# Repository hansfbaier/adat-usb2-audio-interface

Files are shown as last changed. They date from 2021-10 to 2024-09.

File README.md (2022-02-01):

# ADAT USB Audio Interface

FPGA based USB 2.0 High Speed audio interface featuring multiple optical ADAT inputs and outputs

BlockDiagram

## Status / current limitations
* Enumerates as class compliant audio device on Windows and Linux (Mac OS not tested). 2 and 32 channel modes.
* Audio input and output seems to work glitch free.
* Only 48kHz sample rate supported
* Integrated USB2 high speed logic analyzer works
* Runs without dropouts with FlexASIO with a buffer size of 32 samples (0.67ms latency)
* Has a hardware roundtrip latency (USB out -> ADAT out -> cable -> ADAT in -> USB in)
  of 2-3 USB2 microframes which is about 0.25ms to 0.375 ms
* Both headphone DACs on the board work now. In two channel mode, they are both wired to channels 0/1.
  In 36 channel mode DAC1 is wired to channels 0/1 and DAC2 to channels 2/3
* Both USB PHYs now are operational. USB1 has access to all 32 ADAT I/Os and has 4 extra channels to/from USB2.
  USB2 enumerates as a 4-channel sound card which sends/receives audio to/from USB1
* Both USB interfaces will also enumerate as USB MIDI devices and send each other MIDI
* The current board design has not been designed with the case in mind: In the current version of the case,
  only ADAT-cables with thin connectors will fit into the holes. Cables with fat connectors will hit the case
  wall before they can be fully inserted. This will be fixed in a future iteration of the PCB and case.
* The current case design lacks a guide channel for the LED light pipes. Therefore there is considerable bleed
  from lightpipes into each other, and they also can't be positioned exactly over the LEDs.
  Will be fixed in the next version of the case.
* Limitation: Currently audio input will not work properly when audio output is inactive.
  This should not be a problem for most uses (VoIP, Videoconference, DAW recording).
  If you have an important use case which needs this, please file an issue.

## Hardware
The current board design is a custom development board,
based on the QMTech core FPGA boards.
Once the chip shortage is over, it is planned to move to
a complete custom design, including the FPGA.

P1173938



## How to build
1. Download and install [Intel Quartus Lite](https://fpgasoftware.intel.com/?edition=lite)
2. put the bin/ directory of Quartus into your PATH variable:
```bash
export PATH=$PATH:/opt/intelFPGA_lite/21.1/quartus/bin/
```
Of course you need to adjust this to the install directory and version of your particular installation.

3. Set up python venv and install requirements:
```bash
$ cd gateware/
$ ./initialize-python-environment.sh
$ cd ..
```

4. Activate the venv and build
```bash
$ source ./gateware/venv/bin/activate
$ python3 gateware/adat_usb2_audio_interface.py --keep
```

This will create a directory named build/ and after a successful build will directly
try to load the generated bitstream into the FPGA, if an USB-Blaster is connected.
Or, you can flash the bitstream manually, by opening the Quartus GUI with:
```bash
quartus build/*.qpf
```
and then open the programmer application from there.
Alternatively you could directly start the programmer with:
```bash
quartus_pgmw
```

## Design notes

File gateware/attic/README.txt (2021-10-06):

This directory contains platform files which are not maintained
anymore, but still can serve as examples on how to run on
other boards.

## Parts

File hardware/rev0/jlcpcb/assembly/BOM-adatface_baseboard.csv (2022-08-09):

Comment | Designator | Footprint | LCSC
10k | R10,R3,R4,R5,R6,R9 | R_0603_1608Metric | C25804
USB3320 | U5,U6 | QFN-32-1EP_5x5mm_P0.5mm_EP3.3x3.3mm | C132156
PLR135_T8 | U1,U2,U3,U4 | PLR135-T8_PLT133-T8 | C133351
47uH | L1,L2,L3,L4 | L_0805_2012Metric | C14304
100n | C1,C12,C14,C15,C17,C2,C20,C3,C4,C5,C6,C7,C8 | C_0603_1608Metric | C14663
1u | C11,C13 | C_0603_1608Metric | C15849
10u | C21 | C_0805_2012Metric | C15850
Connector_USB_C_Receptacle_USB2.0 | J4,J5 | USB_C_Receptacle_XKB_U262-16XN-4BVC11 | C165948
1.5A | FB1 | L_1206_3216Metric | C16902
10n | C19 | C_0805_2012Metric | C1710
1k | R1,R11,R2,R21,R23,R25,R8 | R_0603_1608Metric | C21190
Schottky | D12,D13 | D_SMA | C22452
red | D1 | LED_0603_1608Metric | C2286
1M | R12,R7 | R_0603_1608Metric | C22935
2k | R24,R26 | R_0603_1608Metric | C22975
8k06 1% | R17,R18 | R_0603_1608Metric | C23112
5k1 | R13,R14,R15,R16 | R_0603_1608Metric | C23186
2u2 | C10,C16,C18,C9 | C_0603_1608Metric | C23630
ME6212C18M5G | U7 | SOT-23-5 | C236669
10k | R19,R20 | R_0603_1608Metric | C25804
PLT133_T8 | TR1,TR2,TR3,TR4 | PLT133_T8 | C2940206
yellow | D10,D11,D2,D7 | LED_0603_1608Metric | C72038
green | D3,D4,D5,D6,D8,D9 | LED_0603_1608Metric | C72043
MountingHole | H3 | MountingHole_3.2mm_M3_Pad_Via
MountingHole | H4 | MountingHole_3.2mm_M3_Pad_Via
Conn_02x32_Odd_Even | J3 | PinHeader_2x32_P2.54mm_Vertical
Conn_01x26_Male | J7 | PinHeader_1x26_P2.54mm_Horizontal
Conn_01x06_Male | J6 | PinHeader_1x06_P2.54mm_Vertical
TestPoint | TP5 | TestPoint_Pad_D1.5mm
Conn_01x01_Male | J9 | PinHeader_1x01_P2.54mm_Horizontal
MountingHole | H2 | MountingHole_3.2mm_M3_Pad_Via
Conn_01x06_Male | J1 | PinHeader_1x06_P2.54mm_Vertical
Conn_01x01_Male | J8 | PinHeader_1x01_P2.54mm_Horizontal
MountingHole | H1 | MountingHole_3.2mm_M3_Pad_Via
Conn_02x32_Odd_Even | J2 | PinHeader_2x32_P2.54mm_Vertical
Conn_01x04_Male | J11 | PinHeader_1x04_P2.54mm_Horizontal
Conn_01x04_Male | J10 | PinHeader_1x04_P2.54mm_Horizontal

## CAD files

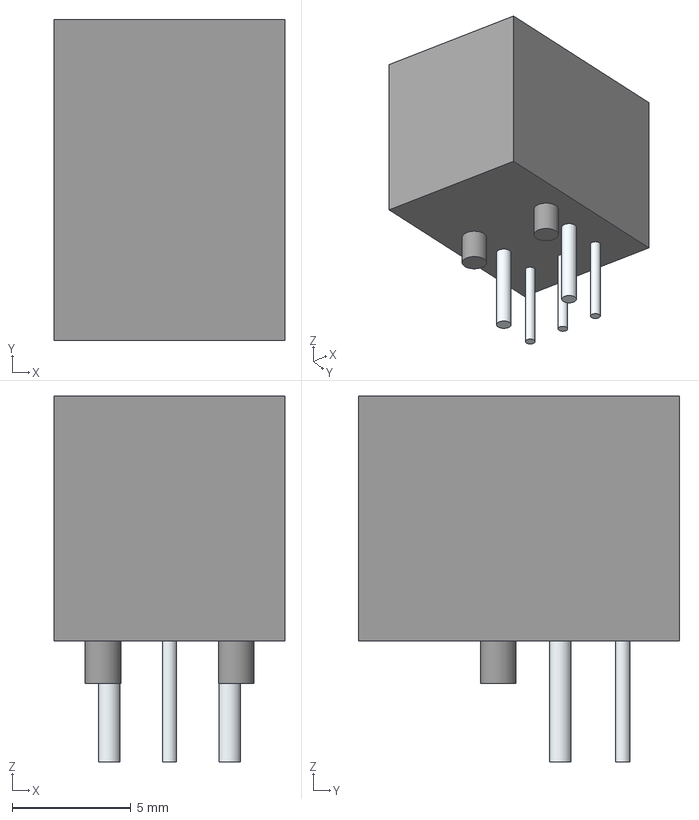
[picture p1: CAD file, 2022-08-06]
hardware/rev0/3d/PLR135_T8.stp
9.70 x 13.5 x 15.4 mm
Lugs
Leads

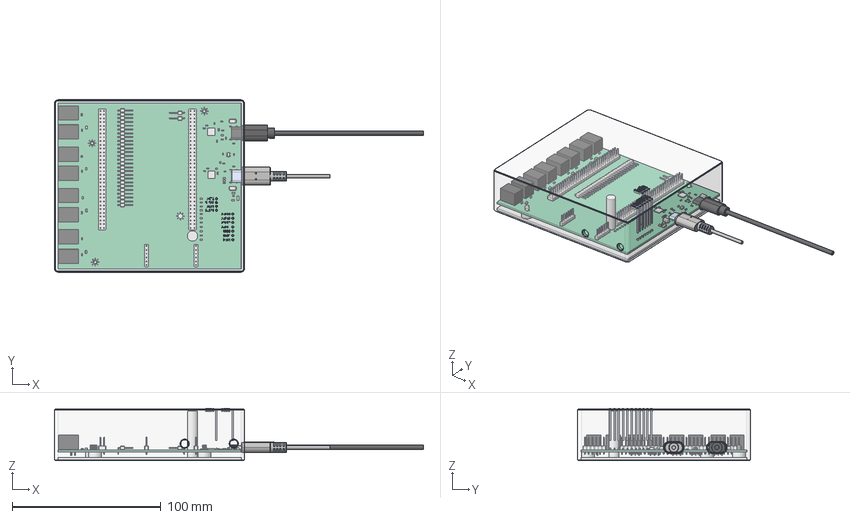
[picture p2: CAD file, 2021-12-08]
hardware/rev0/case/ADATFaceCase.FCStd
248.0 x 116.0 x 35.3 mm
BottomLeftMount x 6
BottomRightSupport x 2
CaseTopBody
ADAT2String x 2
ADAT1String x 2
ADAT4String x 2
ADAT3String x 2
USB2String x 2
USB1String x 2
HostString x 2
SUSP1String x 2
ACT1String x 2
SUSP2String x 2
ACT2String x 2
Pcb_9d1f001
C10_C_0603_1608Metric_8749e7496106 x 19
R4_R_0603_1608Metric_fe543ee5e4d010 x 25
U1_PinsNBody_5129bfe4b11c001 x 8
L3_L_0805_2012Metric_84542feedeaa001 x 4
FB1_L_1206_3216Metric_a2b608e0402e001
U7_SOT_23_5_cd6b5ce1bda009
D4_LED_0603_1608Metric_7710a5fe2378 x 11
C21_C_0805_2012Metric_58affebfe3e007 x 2
J3_PinHeader_2x32_P254mm_Vertical_827fe640e859 x 2
J7_PinHeader_1x26_P254mm_Horizontal_f74b46463a060
J6_PinHeader_1x06_P254mm_Vertical_6c3610613bb005 x 2
J4_HRO TYPE-C-31-M-12 v4_f2d876df633f001 x 2
D12_D_SMA_4ec7c990d17b001 x 2
J9_PinHeader_1x01_P254mm_Horizontal_e01027700fcd001 x 2
U5_QFN_32_1EP_5x5mm_P05mm_EP33x33mm_b3bbaa4d1dda001 x 2
USB Plug
Inner
Outer
USB Tipo C
Lightpipe x 7
DebugLightpipe x 4
BottomMountBody x 6
BottomSupport x 2
CaseBottomBody
M3 x 0.5mm Thread 6mm LONG SOCKET HEAD CAP SCREW x 3

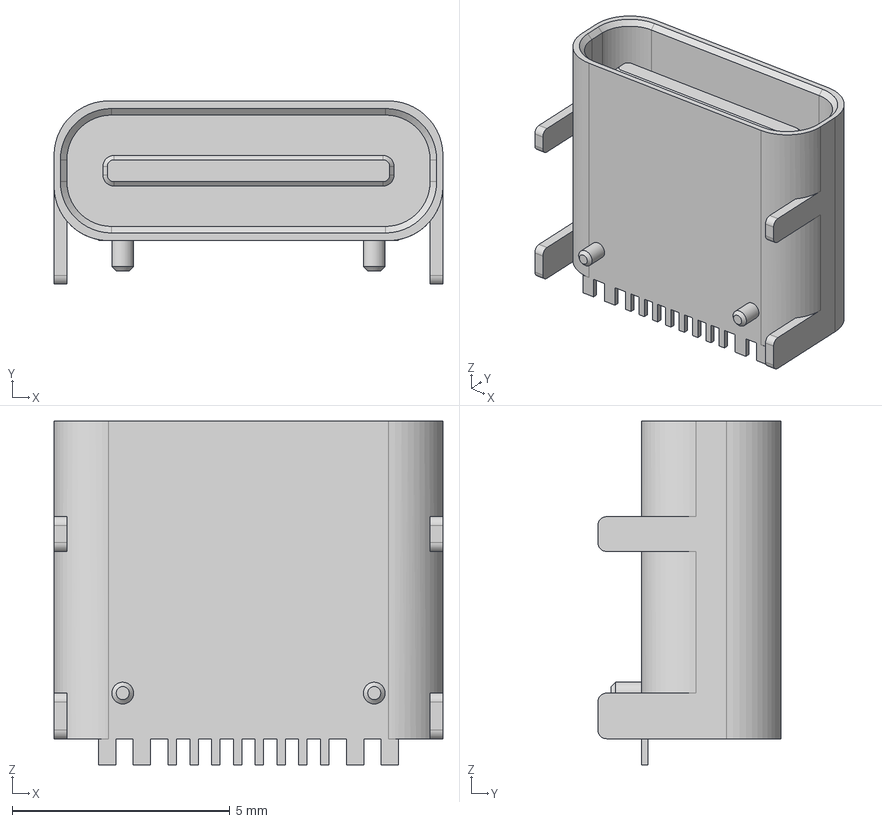
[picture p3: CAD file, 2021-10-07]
hardware/rev0/3d/HRO TYPE-C-31-M-12.step
8.94 x 4.21 x 7.90 mm

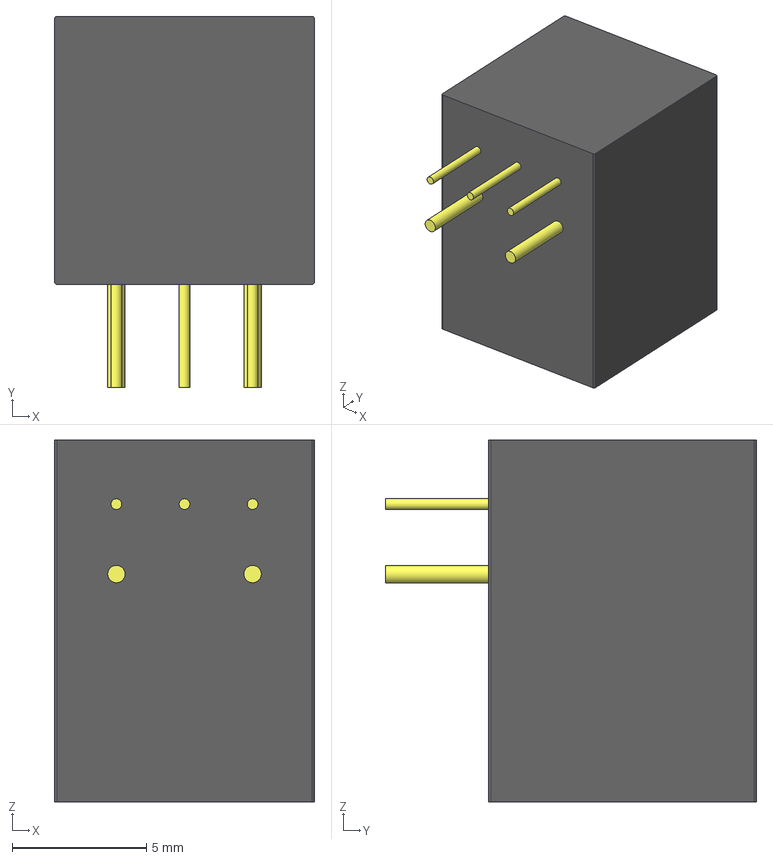
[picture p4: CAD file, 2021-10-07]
hardware/rev0/3d/PLT133_T10.step
9.70 x 13.8 x 13.5 mm

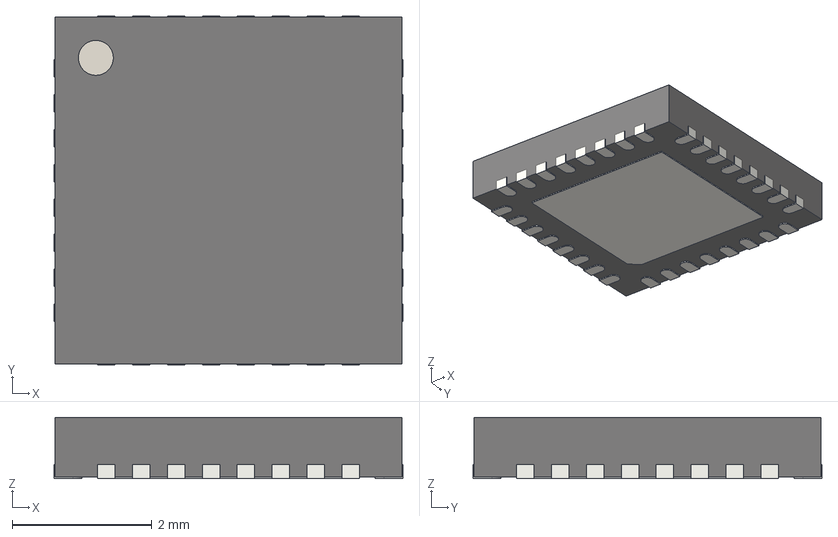
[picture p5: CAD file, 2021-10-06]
hardware/rev0/3d/QFN-32-1EP_5x5mm_P0.5mm_EP3.3x3.3mm.step
5.00 x 5.00 x 0.875 mm

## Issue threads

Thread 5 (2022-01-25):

USB interface

danielkucera, 2022-01-25:
Hello,
I like this project and would like to reproduce it with qmtech spartan 6 board.
Can I use USB3300 for USB interface or is there some special feature of 3320 being used?

If so, don't you happen to have one extra unpopulated PCB to sell?

Thank you.

hansfbaier, 2022-01-25:
The USB3300 cannot be clocked by the FPGA, it needs its own clock, so we really need the USB3320

danielkucera, 2022-01-25:
Thank you, and what about the PCB to sell?

hansfbaier, 2022-01-25:
@danielkucera  I edited the post above, please read...

danielkucera, 2022-01-25:
Okay, I'll try that first. Thanks.

hansfbaier, 2022-01-25:
Also, I don't have a platform file for the Spartan 6 boards here:
https://github.com/amaranth-community-unofficial/amaranth-boards
You would have to write one.

danielkucera, 2022-01-25:
I stuck on this error:
```
ERROR:HDLCompiler:1654 - "/tmp/tmp4pxd9uc8/top.v" Line 13503: Instantiating <audiopll> from unknown module <ALTPLL>
Module car remains a blackbox, due to errors in its contents
```
and then I realized porting to Xilinx would require whole clock generation rewrite:
https://github.com/hansfbaier/adat-usb2-audio-interface/blob/main/gateware/car.py#L49

So putting this on hold indefinitely.

But I wonder if there is a way in amaranth to write a portable code to generate clocks...

hansfbaier, 2022-01-26:
No amaranth does not provide that.
The PLLs of each FPGA are quite different. Even Cyclone V is not compatible with Cyclone IV.
Try building with --keep
To examine the build
.
ALTPLL is for Intel FPGAs, that won't work with Xilinx

fritzbauer, 2022-01-26:
There is an open issue to allow for portable clocks in amaranth: https://github.com/amaranth-lang/amaranth/issues/425

danielkucera, 2022-01-26:
You mean like this?
```
python3 adat_usb2_audio_interface.py --keep
```

The result is the same.

hansfbaier, 2022-01-26:
Yes, but then you can look into the log files to find out about why it
failed

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

Closed 2022-01-25.

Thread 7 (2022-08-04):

S/PDIF support?

nikitalita, 2022-08-04:
I realize that S/PDIF is a different protocol and may take some effort to work because of variable clock speeds, but is this something that you are thinking about implementing in the future?

hansfbaier, 2022-08-04:
Yes, I have been thinking about it, but it's not a priority at the moment.

nikitalita, 2022-08-05:
I may do just that. Is the current board revision tested and working? Might order it off of JLCPCB.

nikitalita, 2022-08-05:
Also, I note that the board that you have in the picture with the 5CEFA2F23 is no longer in stock or manufactured: https://www.aliexpress.com/item/2252799820307397.html

There's another board with an 5CEFA5F23 and more SRAM available; will this work?
https://www.aliexpress.com/item/3256801596388647.html

hansfbaier, 2022-08-06:
I actually don't recommend the Cyclone V, any Cyclone IV board from QMTech is actually better.

hansfbaier, 2022-08-06:
This will be the best value for money, hands down: https://www.aliexpress.com/item/1005004065727282.html
I already have that board, but I still need to write a board support file for that.
I actually developed most of the current code with this board: https://www.aliexpress.com/item/32949281189.html

nikitalita, 2022-08-06:
> This will be the best value for money, hands down: https://www.aliexpress.com/item/1005004065727282.html I already have that board, but I still need to write a board support file for that. I actually developed most of the current code with this board: https://www.aliexpress.com/item/32949281189.html

Ok, I will get the first one.

Are there any special requirements for ordering the PCB off of JLCPCB? For example, is this a fixed-impedance board?

hansfbaier, 2022-08-06:
No it isn't.
Four layer board with standard settings.

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

hansfbaier, 2025-03-10:
@rusk911 EP4CE6 is too small, the EP4CE15 will fit

Closed 2022-10-24.

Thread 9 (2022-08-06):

Board exceeds JLCPCB capabilities

nikitalita, 2022-08-06:
Got this message from JLCPCB and they cancelled my order:

"After marking the hole compensation of the original 0.4/0.6 mm, the minimum hole distance is only about 0.17 mm, and the minimum hole distance line is only about 0.08, which exceeds our capabilities. (the minimum hole distance of different networks must be greater than 0.33 mm , the hole distance line must be greater than 0.23 mm)"

I did notice that the visa and tracks were awfully close to each other, but i figured you had submitted this to JLCPCB before so i didn’t think it was an issue.

I’d do this myself, but modifying this design to fix this issue messes with it far more than I am comfortable with.

the full list of capabilities can be found here: https://jlcpcb.com/capabilities/Capabilities

hansfbaier, 2022-08-06:
Did they send a picture with an example?
I got something like this in the past, it looks I will have to update some of  the design rules.

nikitalita, 2022-08-06:
Not that I can see; I’ll ask support if they have them

hansfbaier, 2022-08-06:
@nikitalita I pushed a new version, with bigger hole-to-hole clearance. Try that one again.

nikitalita, 2022-08-06:
Did you mean to get rid of the ground plane on F.Cu?

nikitalita, 2022-08-06:
also, I'm still noticing some spacing issues with copper to hole, despite the board setup having the correct constraints, I'm not sure why ERC is not picking this up:
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

hansfbaier, 2022-08-08:
> Did you mean to get rid of the ground plane on F.Cu?

No that was an accident. I'll put it back in.

hansfbaier, 2022-08-08:
That is weird, the ground plane now has only tiny spaces to normal tracks,
although I already put 0.3mm clearance in the ground plane parameters:
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

nikitalita, 2022-08-08:
I had noticed that too; I am not certain how to fix that.

hansfbaier, 2022-08-08:
Looks like a bug in recent KiCAD :(
No parameters seem to influence it.

hansfbaier, 2022-08-08:
I filed an issue at KiCAD, and posted on Twitter.
Let's see how that goes
https://gitlab.com/kicad/code/kicad/-/issues/12184
https://twitter.com/hansfbaier/status/1556534673005690882

hansfbaier, 2022-08-08:
A kind soul on Twitter gave the right hint:
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

hansfbaier, 2022-08-08:
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

hansfbaier, 2022-08-08:
But it changing that didn't do anything. grr

hansfbaier, 2022-08-08:
hmmm
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

hansfbaier, 2022-08-08:
This one might be it:
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

hansfbaier, 2022-08-08:
Ha! I deleted all the custom rules, then the rules set in the GUI apply.
The 'Custom rules' were probably the import from the previous version.
We have learned something!

hansfbaier, 2022-08-08:
Now THAT looks more like it!
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

hansfbaier, 2022-08-08:
Committed interim state. Now there is a ton of DRC violations.
Homework for tomorrow.

hansfbaier, 2022-08-09:
Ah minimum spacing should be this:
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
Had to fix a couple of traces, now it should be fine.

nikitalita, 2022-08-09:
Excellent, I’ll double check it

hansfbaier, 2022-08-09:
@nikitalita I just pushed a new version, that should be good now. Still did some modifications and added some ground headers. Good for hacking/prototyping

hansfbaier, 2022-08-09:
Should be ready to fab I hope, but it won't hurt if you check again.

hansfbaier, 2022-08-09:
@nikitalita I just pushed the latest version.
Please pull and check again.

hansfbaier, 2022-08-09:
The old version works well with all its weaknesses, so let's hope this one screams!

hansfbaier, 2022-08-09:
@nikitalita BTW, these DAC boards are dirt cheap and they sound fantastic!
https://www.aliexpress.com/item/1005002898278583.html

hansfbaier, 2022-08-09:
And they are in stock again!
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

hansfbaier, 2022-08-09:
and cost twice as much as the module in single quantities (gasp).

nikitalita, 2022-08-09:
lol, I already bought like three of them for 12 bucks

nikitalita, 2022-08-11:
The board has passed review and is in production; when I get it, I’ll let you know how it works

hansfbaier, 2022-08-11:
@nikitalita Great! When it works I'll cut a release

nikitalita, 2022-08-28:
I have tested the board; I know that the DAC works at least, I still have to test ADAT input and output.

I do notice a couple issues while soldering on the headers:

- There are ground vias that are too close to the headers for the cyclone board on the USB side. This makes it very easy to accidentally bridge one of the Pins to ground during assembly. I recommend we either move or get rid of the vias that are less than 2mm from the header PTHs.
- We should specify that the cyclone board headers on the ADATiface board be female. It’s very easy to install the male headers slightly crooked on the ADATiface and it is harder to get the core board in with female sockets on it.
- we should place orientation indicators for the core board on the ADATiface board; it’s too easy to install it in reverse. Maybe something like an indicator of which direction the DC power plug goes?

hansfbaier, 2022-08-30:
Can you post a screenshot of what vias you are talking about?
I actually use female headers on the board :] They have the same footprint anyway.
I think it would be best to just delete the silkscreen of the headers, because they have the same footprint anyway.
Orientation indicators would be a good idea.

Closed 2022-10-24.

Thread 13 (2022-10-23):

Port to LUNA board

icb-, 2022-10-23:
Would it be possible to port this to the [LUNA board](https://www.crowdsupply.com/great-scott-gadgets/luna)?

The 8 in and out optical ports should fit comfortably on one of the two available PMOD connectors (though power draw may become an issue), and the two DACs on the other.

hansfbaier, 2022-10-23:
Yes I think that should be entirely possible.
I already ported the design to an ECP5 based board (colorlight i5/i9).
But the ADAT transmitter doesn't work there yet. Once that bug is fixed
there would be no problem.

Best regards,
Hans

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

hansfbaier, 2022-11-11:
I think this question has been sufficiently answered. Closing this issue.

Closed 2022-11-11.

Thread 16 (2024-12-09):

Files for assembly?

JomerDev, 2024-12-09:
Hello, I am very interested in this project and am planning on ordering some from jlcpcb.
However, when I take the files generated in the jlcpcb/gerber folder and upload them it looks like no part is marked for assembly?
Even if I enable assembly on jlcpcb it looks like nothing changes.
I haven't ordered parts with assembly before so there is a high chance I'm just missing something, still, could I get some pointers on how to order the board?

hansfbaier, 2024-12-09:
You need to upload the bom and cpl files

JomerDev, 2024-12-09:
🤦‍♂️ I am an idiot. I'm so used to the "Save to cart" button being there that I didn't even realize that I need to go to the next page to upload the assembly files and instead kept looking for a way to upload them on the first page.
Thank you!

Closed 2024-12-09.

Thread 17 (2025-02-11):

Device only shows up with two channels, how to switch mode

JomerDev, 2025-02-11:
Hello, after finally finding time to flash the FPGA I'm now trying to set up the adatface. It shows up as usb audio input and output, however whatever I do I never get more than the two channels. I've tried multiple hours now and am fairly lost what I need to do to make this work.

This is on windows 10

hansfbaier, 2025-02-11:
You have to use an ASIO driver for Windows, that sets the USB device into the proper altsetting for multichannel.
I heard someone had success with https://github.com/dechamps/FlexASIO
There is also https://github.com/koord-live/KoordASIO
which looks great, but I have no experience with.

JomerDev, 2025-02-12:
Hey  @hansfbaier,
thank you for the quick answer. FlexASIO also had issues with multiple channels, but I got that part to work with ASIO4All.
I do however have another problem where I don't really know what I can do. Sending audio via ADAT now works fine, over all channels, however it seems I can't receive anything. I've tried it with a Yamaha mixer, I can confirm that channels sent via ADAT are received, I can hear everything via the phones plug but no audio ever gets received back.
I even tried to plug a small ADAT cable from a sending port on the PCB to an receiving port while audio was sent, but I don't get any audio back. I tried it with multiple ports, same issue. Do you have any idea?
(Also, the ADAT LEDs never really glow even if audio is sent, don't know if that has any significance. The USB and act/susp LEDs work fine)

JomerDev, 2025-02-12:
Also, I tried to use the ila script to see if anything would look off, but I couldn't get that to work either, even in the venv, something about a pickled file it tries to unpickle not actually being there

hansfbaier, 2025-02-12:
The ila is really only for development, so you need to know what you are doing with that one. Receiving ADAT worked for me on Linux. Can't support Windows really, because I did not test it there yet. I heard others got it working there yet.

JomerDev, 2025-02-14:
Alright, so I checked everything else again, even got FlexASIO to work, but I still won't get any audio in from the AdatFace. I've checked with another device that there are audio signals coming in via the ADAT cable. So it sadly has to be some issue with the device.
If there is any way I can help to debug and test it please do let me know, I'd love for this to fully work

JomerDev, 2025-02-14:
So my current setup is PC -> ADATFace -> Yamaha Mixer -> ADATFace -> PC
I've tried changing ADAT settings in the mixer, but they only affect the ADAT input, meaning the mixer gets no audio and complains about ADAT sync issues. So I set it back to the mixer receiving the clock from the ADATFace, and that works for the input. So unless I can somehow change the clock in the ADATFace I don't really know what to change.
And again, I tried connecting the ADAT output from the mixer to an AD/DA transformer and it receives the ADAT Signal fine and plays it, so the signal coming from the mixer is fine as well

hansfbaier, 2025-02-14:
Yes the Mixer needs to sync to the audio interface. Unfortunately I can't really support Windows. It worked for me on Linux

icb-, 2025-02-14:
It might help if you could try with a Linux PC, even just with an Ubuntu live image so you don't have to install anything permanent. https://ubuntu.com/tutorials/try-ubuntu-before-you-install

JomerDev, 2025-02-15:
Ok, so I've tried it with Ubuntu. My Linux isn't great, especially around audio, but I got the ADATFace to send audio to the mixer, as I did on Windows. So that part works as it did before. I could not get it to receive audio from the mixer through the ADATFace into Ubuntu. As a final test, I set both the default input and output sound device to the ADATFace and connected the input and output of the ADAT 1 interface together - as a sort of cheap loopback mechanism. I could see through Ubuntu that sound was sent, but nothing was received. So it seems like it isn't working (for me) under linux either

fritzbauer, 2025-02-15:
Could you maybe boot your ubuntu system, log in, wait 30s to have everything settled, plug in the interface and post the output of `sudo dmesg`?
What sounds odd though, that you are able to send via ADAT, without the LEDs actually glowing?! Usually you should see red light indeed.

JomerDev, 2025-02-16:
@fritzbauer
Done. The relevant part (everything that was logged after plugging it in) is
```
[  328.619736] usb 4-2: new high-speed USB device number 7 using xhci_hcd
[  328.747273] usb 4-2: config 1 interface 3 altsetting 0 bulk endpoint 0x3 has invalid maxpacket 64
[  328.747292] usb 4-2: config 1 interface 3 altsetting 0 bulk endpoint 0x83 has invalid maxpacket 64
[  328.748651] usb 4-2: New USB device found, idVendor=1209, idProduct=ada1, bcdDevice= 0.01
[  328.748664] usb 4-2: New USB device strings: Mfr=1, Product=2, SerialNumber=3
[  328.748672] usb 4-2: Product: ADATface (USB1)
[  328.748678] usb 4-2: Manufacturer: OpenAudioGear
[  328.748684] usb 4-2: SerialNumber: 0
[  328.846123] usb 4-2: Quirk or no altset; falling back to MIDI 1.0
[  328.847133] usbcore: registered new interface driver snd-usb-audio
```

[dmesg.log](https://github.com/user-attachments/files/18816542/dmesg.log)

JomerDev, 2025-02-24:
Also, I've tested all LEDs, they all work individually. But when running with the FPGA, only the USB1, USB2, ACT* and SUSP* LEDs seem to do anything. As my issue happens on linux as well, could this github issue be reopened?
If there is anything I can do to help diagnose the issue, please do let me know!

Closed 2025-02-11.

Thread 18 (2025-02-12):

Interface USB-2.0 Audio <-> ADAT ?

pltrz, 2025-02-12:
Using this interface, could I convert a USB-2.0 Audio signal to Optical, so that I can use the optical i/o on an audio interface?

I have a Quad Cortex, that acts a class-compliant USB-2.0 Audio Interface (8 channels in, 8 channels out, 48000 Hz, 24 bit). Unfortunately, no built-in Optical I/O.

I plan on upgrading my main audio interface in the future. Been considering the RME Fireface UCX II, since it has ADAT in/out expansion.

Can I take this USB signal from my Quad Cortex, and convert it into ADAT i/o, and use the ADAT i/o expansion on a Fireface UCX II?

This way, I avoid using the analog out on the Quad Cortex (Digital->Analog conversion) and analog inputs on the interface (Analog->Digital conversion). I want to avoid the extra D/A A/D conversion.

I looked at the MCHStreamer by MiniDSP, which seems perfect. It's a USB<->Optical audio interface. But, I reached the company and they advised me that since my Quad Cortex and the MCHStreamer are both "USB Devices" - meaning, neither are "USB Hosts", it would not work. Since, in a USB connection, one device must act as a host. (https://www.minidsp.com/products/usb-audio-interface/mchstreamer).

icb-, 2025-02-12:
This is also a USB device, not host.

icb-, 2025-02-12:
Ah, yes. I was trying to track that project down (I can never remember its name.) It doesn't have any optical support, but with two PMOD sockets, one could use an optical audio PMOD (though a quick search has only turned up a few TX boards, nothing with RX)

hansfbaier, 2025-02-12:
Yes, tiliqua does not have optical, so you definitely would have to backport this here, which requires some development effort.

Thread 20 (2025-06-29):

Reproduction instructions

capocasa, 2025-06-29:
Hello Hans, thanks for making this!!!

I'd like to have a go and reproduce it! But I wanted to confirm I have the correct understanding of what to do, if I may. It'll get mounted on a 17" rack drawer so no case.

- Place a JLCPCB order using files in jlcpcb folder, which contains gerber and BOM
- Order a Cyclone IV EP4CE55 dev board
- Stick the FPGA into the PCB
- Run build process from README
- add firmware to alsa-firmware folder and use

Is this about right?

Thanks! Carlo

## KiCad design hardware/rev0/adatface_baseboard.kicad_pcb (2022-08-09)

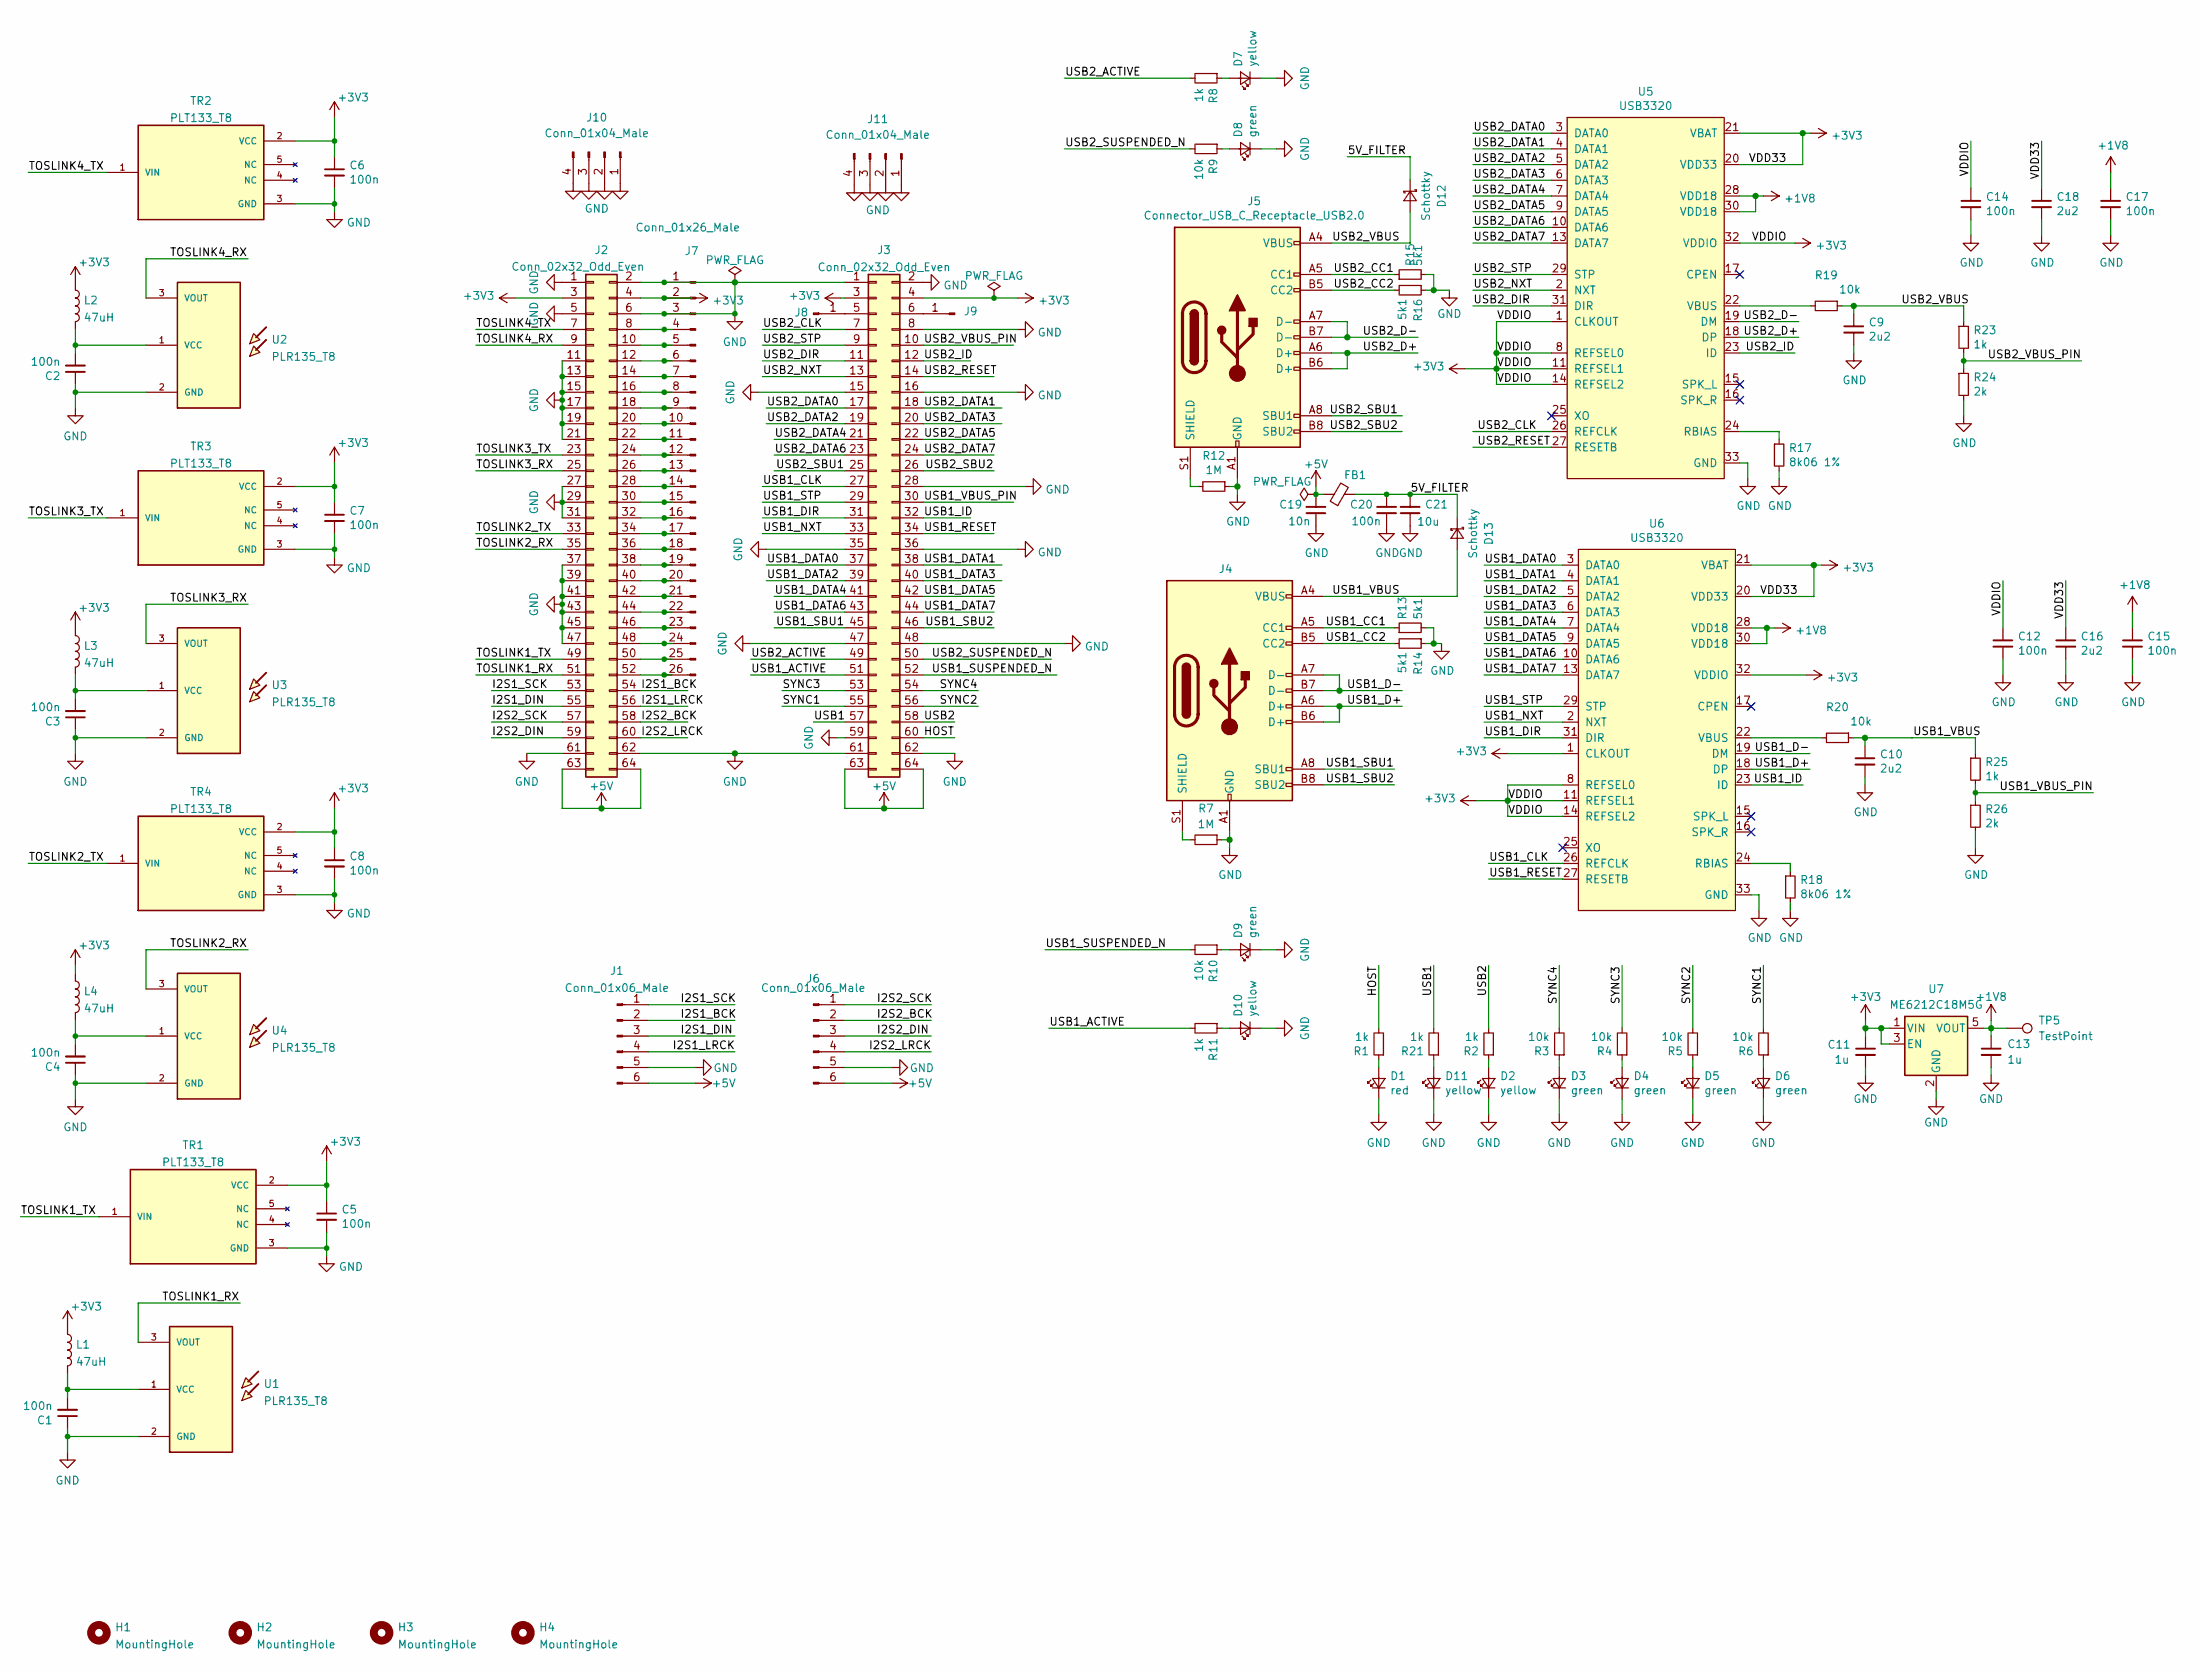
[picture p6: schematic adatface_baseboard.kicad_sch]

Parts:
C1, C2, C3, C4, C5, C6, C7, C8, C12, C14, C15, C17, C20: 100n; C_0603_1608Metric; LCSC C14663
C9, C10, C16, C18: 2u2; C_0603_1608Metric; LCSC C23630
C11, C13: 1u; C_0603_1608Metric; LCSC C15849
C19: 10n; C_0805_2012Metric; LCSC C1710
C21: 10u; C_0805_2012Metric; LCSC C15850
D1: red; LED_0603_1608Metric; LCSC C2286
D2, D7, D10, D11: yellow; LED_0603_1608Metric; LCSC C72038
D3, D4, D5, D6, D8, D9: green; LED_0603_1608Metric; LCSC C72043
D12, D13: Schottky; D_SMA; LCSC C22452
FB1: 1.5A; L_1206_3216Metric; LCSC C16902
H1, H2, H3, H4: MountingHole; MountingHole_3.2mm_M3_Pad_Via
J1, J6: Conn_01x06_Male; PinHeader_1x06_P2.54mm_Vertical
J2, J3: Conn_02x32_Odd_Even; PinHeader_2x32_P2.54mm_Vertical
J4, J5: Connector_USB_C_Receptacle_USB2.0; USB_C_Receptacle_XKB_U262-16XN-4BVC11; LCSC C165948
J7: Conn_01x26_Male; PinHeader_1x26_P2.54mm_Horizontal
J8, J9: Conn_01x01_Male; PinHeader_1x01_P2.54mm_Horizontal
J10, J11: Conn_01x04_Male; PinHeader_1x04_P2.54mm_Horizontal
L1, L2, L3, L4: 47uH; L_0805_2012Metric; LCSC C14304
R1, R2, R8, R11, R21, R23, R25: 1k; R_0603_1608Metric; LCSC C21190
R3, R4, R5, R6, R9, R10, R19, R20: 10k; R_0603_1608Metric; LCSC C25804
R7, R12: 1M; R_0603_1608Metric; LCSC C22935
R13, R14, R15, R16: 5k1; R_0603_1608Metric; LCSC C23186
R17, R18: 8k06 1%; R_0603_1608Metric; LCSC C23112
R24, R26: 2k; R_0603_1608Metric; LCSC C22975
TP5: TestPoint; TestPoint_Pad_D1.5mm
TR1, TR2, TR3, TR4: PLT133_T8; PARTREV 5
U1, U2, U3, U4: PLR135_T8; PLR135-T8_PLT133-T8
U5, U6: USB3320; QFN-32-1EP_5x5mm_P0.5mm_EP3.3x3.3mm; LCSC C132156
U7: ME6212C18M5G; SOT-23-5; LCSC C236669

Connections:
+1V8: C13.1, C15.1, C17.1, TP5.1, U5.28 (VDD18), U5.30 (VDD18), U6.28 (VDD18), U6.30 (VDD18), U7.5 (VOUT)
+3V3: C5.1, C6.1, C7.1, C8.1, C11.1, C12.1, C14.1, C16.1, C18.1, J2.3, J2.4, J3.3, J3.4, J7.2, L1.1, L2.1, L3.1, L4.1, TR1.2 (VCC), TR2.2 (VCC), TR3.2 (VCC), TR4.2 (VCC), U5.1 (CLKOUT), U5.8 (REFSEL0), U5.11 (REFSEL1), U5.14 (REFSEL2), U5.20 (VDD33), U5.21 (VBAT), U5.32 (VDDIO), U6.1 (CLKOUT), U6.8 (REFSEL0), U6.11 (REFSEL1), U6.14 (REFSEL2), U6.20 (VDD33), U6.21 (VBAT), U6.32 (VDDIO), U7.1 (VIN), U7.3 (EN)
+5V: C19.2, FB1.1, J1.6, J2.63, J2.64, J3.63, J3.64, J6.6
/5V_FILTER: C20.2, C21.2, D12.1 (K), D13.1 (K), FB1.2
/HOST: J3.60, R1.2
/I2S1_BCK: J1.2, J2.54
/I2S1_DIN: J1.3, J2.55
/I2S1_LRCK: J1.4, J2.56
/I2S1_SCK: J1.1, J2.53
/I2S2_BCK: J2.58, J6.2
/I2S2_DIN: J2.59, J6.3
/I2S2_LRCK: J2.60, J6.4
/I2S2_SCK: J2.57, J6.1
/SYNC1: J3.55, R6.2
/SYNC2: J3.56, R5.2
/SYNC3: J3.53, R4.2
/SYNC4: J3.54, R3.2
/TOSLINK1_RX: J2.51, U1.3 (VOUT)
/TOSLINK1_TX: J2.49, TR1.1 (VIN)
/TOSLINK2_RX: J2.35, U4.3 (VOUT)
/TOSLINK2_TX: J2.33, TR4.1 (VIN)
/TOSLINK3_RX: J2.25, U3.3 (VOUT)
/TOSLINK3_TX: J2.23, TR3.1 (VIN)
/TOSLINK4_RX: J2.9, U2.3 (VOUT)
/TOSLINK4_TX: J2.7, TR2.1 (VIN)
/USB1: J3.57, R21.2
/USB1_ACTIVE: J3.51, R11.2
/USB1_CC1: J4.A5 (CC1), R13.1
/USB1_CC2: J4.B5 (CC2), R14.2
/USB1_CLK: J3.27, U6.26 (REFCLK)
/USB1_D+: J4.A6 (D+), J4.B6 (D+), U6.18 (DP)
/USB1_D-: J4.A7 (D-), J4.B7 (D-), U6.19 (DM)
/USB1_DATA0: J3.37, U6.3 (DATA0)
/USB1_DATA1: J3.38, U6.4 (DATA1)
/USB1_DATA2: J3.39, U6.5 (DATA2)
/USB1_DATA3: J3.40, U6.6 (DATA3)
/USB1_DATA4: J3.41, U6.7 (DATA4)
/USB1_DATA5: J3.42, U6.9 (DATA5)
/USB1_DATA6: J3.43, U6.10 (DATA6)
/USB1_DATA7: J3.44, U6.13 (DATA7)
/USB1_DIR: J3.31, U6.31 (DIR)
/USB1_ID: J3.32, U6.23 (ID)
/USB1_NXT: J3.33, U6.2 (NXT)
/USB1_RESET: J3.34, U6.27 (RESETB)
/USB1_SBU1: J3.45, J4.A8 (SBU1)
/USB1_SBU2: J3.46, J4.B8 (SBU2)
/USB1_STP: J3.29, U6.29 (STP)
/USB1_SUSPENDED_N: J3.52, R10.2
/USB1_VBUS: C10.1, D13.2 (A), J4.A4 (VBUS), J4.A9 (VBUS), J4.B4 (VBUS), J4.B9 (VBUS), R20.1, R25.1
/USB1_VBUS_PIN: J3.30, R25.2, R26.1
/USB2: J3.58, R2.2
/USB2_ACTIVE: J3.49, R8.2
/USB2_CC1: J5.A5 (CC1), R15.1
/USB2_CC2: J5.B5 (CC2), R16.2
/USB2_CLK: J3.7, U5.26 (REFCLK)
/USB2_D+: J5.A6 (D+), J5.B6 (D+), U5.18 (DP)
/USB2_D-: J5.A7 (D-), J5.B7 (D-), U5.19 (DM)
/USB2_DATA0: J3.17, U5.3 (DATA0)
/USB2_DATA1: J3.18, U5.4 (DATA1)
/USB2_DATA2: J3.19, U5.5 (DATA2)
/USB2_DATA3: J3.20, U5.6 (DATA3)
/USB2_DATA4: J3.21, U5.7 (DATA4)
/USB2_DATA5: J3.22, U5.9 (DATA5)
/USB2_DATA6: J3.23, U5.10 (DATA6)
/USB2_DATA7: J3.24, U5.13 (DATA7)
/USB2_DIR: J3.11, U5.31 (DIR)
/USB2_ID: J3.12, U5.23 (ID)
/USB2_NXT: J3.13, U5.2 (NXT)
/USB2_RESET: J3.14, U5.27 (RESETB)
/USB2_SBU1: J3.25, J5.A8 (SBU1)
/USB2_SBU2: J3.26, J5.B8 (SBU2)
/USB2_STP: J3.9, U5.29 (STP)
/USB2_SUSPENDED_N: J3.50, R9.2
/USB2_VBUS: C9.1, D12.2 (A), J5.A4 (VBUS), J5.A9 (VBUS), J5.B4 (VBUS), J5.B9 (VBUS), R19.1, R23.1
/USB2_VBUS_PIN: J3.10, R23.2, R24.1
GND: C1.1, C2.1, C3.1, C4.1, C5.2, C6.2, C7.2, C8.2, C9.2, C10.2, C11.2, C12.2, C13.2, C14.2, C15.2, C16.2, C17.2, C18.2, C19.1, C20.1, C21.1, D1.1 (K), D2.1 (K), D3.1 (K), D4.1 (K), D5.1 (K), D6.1 (K), D7.1 (K), D8.1 (K), D9.1 (K), D10.1 (K), D11.1 (K), J1.5, J2.1, J2.2, J2.5, J2.6, J2.11, J2.13, J2.15, J2.17, J2.19, J2.21, J2.27, J2.29, J2.31, J2.37, J2.39, J2.41, J2.43, J2.45, J2.47, J2.61, J2.62, J3.1, J3.2, J3.8, J3.15, J3.16, J3.28, J3.35, J3.36, J3.47, J3.48, J3.59, J3.61, J3.62, J4.A1 (GND), J4.A12 (GND), J4.B1 (GND), J4.B12 (GND), J5.A1 (GND), J5.A12 (GND), J5.B1 (GND), J5.B12 (GND), J6.5, J7.1, J7.3, J10.1, J10.2, J10.3, J10.4, J11.1, J11.2, J11.3, J11.4, R7.1, R12.1, R13.2, R14.1, R15.2, R16.1, R17.2, R18.2, R24.2, R26.2, TR1.3 (GND), TR2.3 (GND), TR3.3 (GND), TR4.3 (GND), U1.2 (GND), U2.2 (GND), U3.2 (GND), U4.2 (GND), U5.33 (GND), U6.33 (GND), U7.2 (GND)
unnamed: C1.2, L1.2, U1.1 (VCC)
unnamed: C2.2, L2.2, U2.1 (VCC)
unnamed: C3.2, L3.2, U3.1 (VCC)
unnamed: C4.2, L4.2, U4.1 (VCC)
unnamed: D1.2 (A), R1.1
unnamed: D2.2 (A), R2.1
unnamed: D3.2 (A), R3.1
unnamed: D4.2 (A), R4.1
unnamed: D5.2 (A), R5.1
unnamed: D6.2 (A), R6.1
unnamed: D7.2 (A), R8.1
unnamed: D8.2 (A), R9.1
unnamed: D9.2 (A), R10.1
unnamed: D10.2 (A), R11.1
unnamed: D11.2 (A), R21.1
unnamed: J2.8, J7.4
unnamed: J2.10, J7.5
unnamed: J2.12, J7.6
unnamed: J2.14, J7.7
unnamed: J2.16, J7.8
unnamed: J2.18, J7.9
unnamed: J2.20, J7.10
unnamed: J2.22, J7.11
unnamed: J2.24, J7.12
unnamed: J2.26, J7.13
unnamed: J2.28, J7.14
unnamed: J2.30, J7.15
unnamed: J2.32, J7.16
unnamed: J2.34, J7.17
unnamed: J2.36, J7.18
unnamed: J2.38, J7.19
unnamed: J2.40, J7.20
unnamed: J2.42, J7.21
unnamed: J2.44, J7.22
unnamed: J2.46, J7.23
unnamed: J2.48, J7.24
unnamed: J2.50, J7.25
unnamed: J2.52, J7.26
unnamed: J3.5, J8.1
unnamed: J3.6, J9.1
unnamed: J4.S1 (SHIELD), R7.2
unnamed: J5.S1 (SHIELD), R12.2
unnamed: R17.1, U5.24 (RBIAS)
unnamed: R18.1, U6.24 (RBIAS)
unnamed: R19.2, U5.22 (VBUS)
unnamed: R20.2, U6.22 (VBUS)

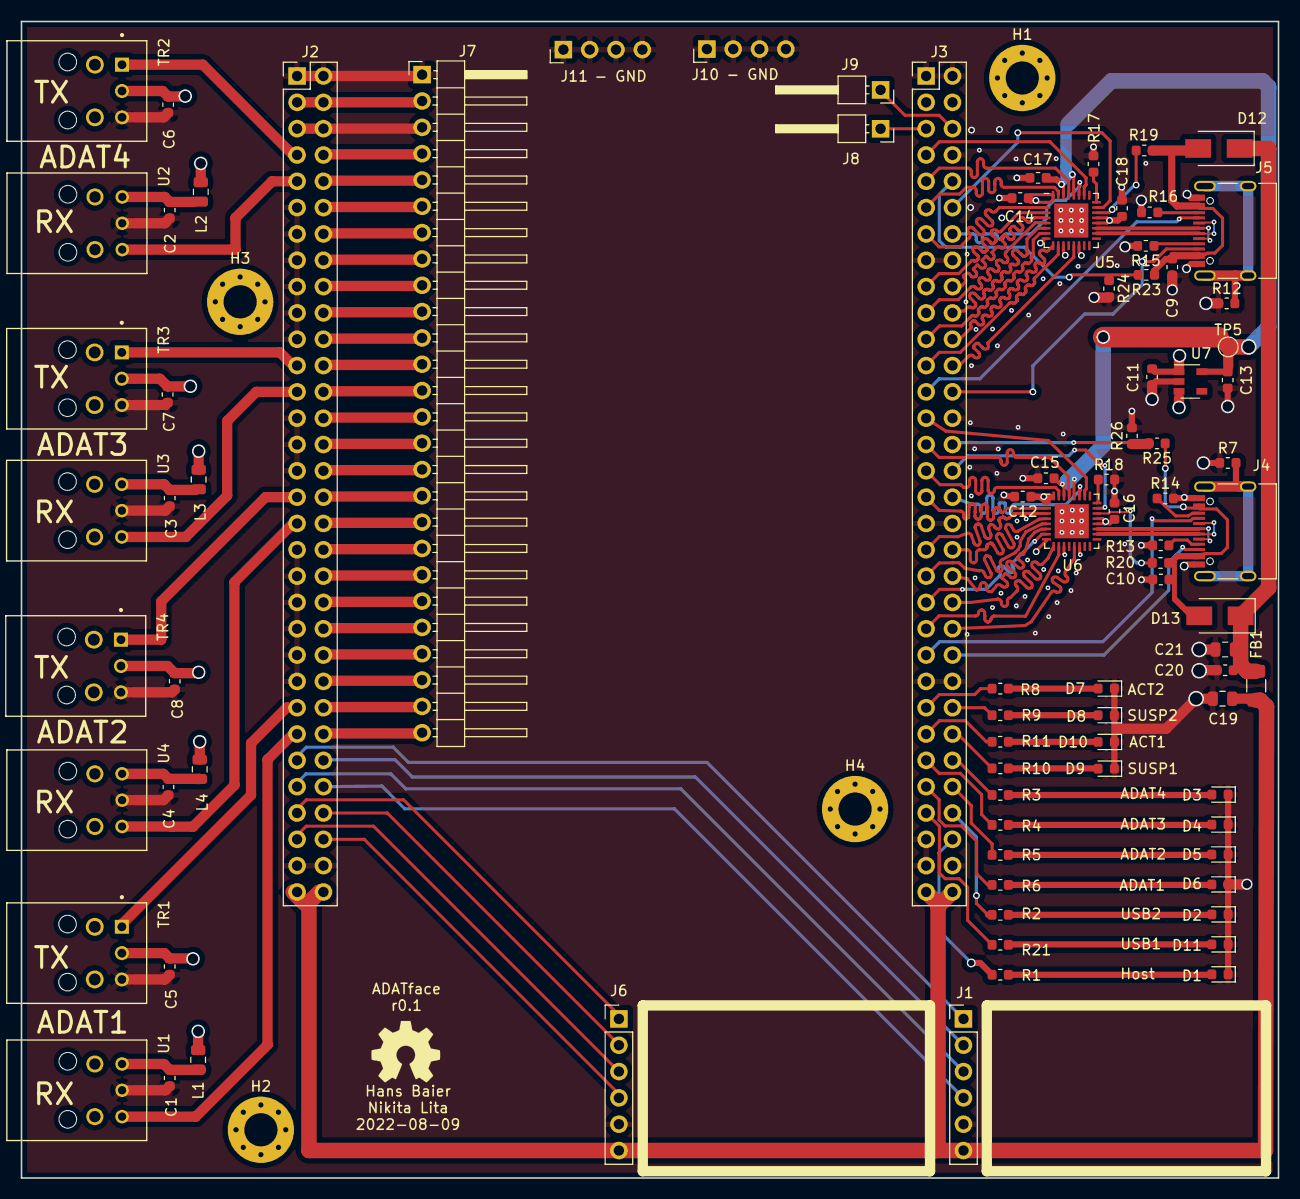
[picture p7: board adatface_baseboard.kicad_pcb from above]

Board: 4 copper layers, 121.3 x 111.6 mm, 92 parts (0 on the bottom side), 122 nets.

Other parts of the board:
N1: OHWLOGO; OSHW-Symbol_6.7x6mm_SilkScreen

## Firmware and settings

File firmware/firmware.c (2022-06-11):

/**
 * Copyright (c) 2020 Great Scott Gadgets <info@greatscottgadgets.com>
 * Copyright (c) 2022 Hans Baier <hansfbaier@gmail.com>
 * SPDX-License-Identifier: BSD-3-Clause
 */


#include <stdbool.h>
#include <stdint.h>
#include "resources.h"

#define ARRAY_SIZE(array) (sizeof(array) / sizeof(*array))

//
// Support functions.
//

/**
 * Transmits a single charater over our example UART.
 */
void print_char(char c)
{
	while(!uart_tx_rdy_read());
	uart_tx_data_write(c);
}

/**
 * Transmits a string over our UART.
 */
void uart_puts(char *str)
{
	for (char *c = str; *c; ++c) {
		if (*c == '\n') {
			print_char('\r');
		}

		print_char(*c);
	}
}

/**
 * Prints a hex character over our UART.
 */
void print_nibble(uint8_t nibble)
{
	static const char hexits[] = "0123456789abcdef";
	print_char(hexits[nibble & 0xf]);
}

/**
 * Prints a single byte, in hex, over our UART.
 */
void print_byte(uint8_t byte)
{
	print_nibble(byte >> 4);
	print_nibble(byte & 0xf);
}

//
// Core application.
//

int main(void)
{
	uart_puts("SoC started! (built: " __TIME__ ")\n");

	while (1) {
		for(int i=0; i<(1<<23); i++) ;
		uart_puts("Ping...\r\n");
	}
}

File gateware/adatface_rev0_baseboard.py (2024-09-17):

from amaranth.build import *
from amaranth_boards.resources import *

class ADATFaceRev0Baseboard:
    @staticmethod
    def resources(attrs, colorlight=False):
        return [
            # LEDS
            Resource("leds", 0,
                Subsignal("host",       Pins ("J_3:60", dir="o")),
                Subsignal("usb1",       Pins ("J_3:57", dir="o")),
                Subsignal("usb2",       Pins ("J_3:58", dir="o")),
                Subsignal("sync1",      Pins ("J_3:55", dir="o")),
                Subsignal("sync2",      Pins ("J_3:56", dir="o")),
                Subsignal("sync3",      Pins ("J_3:53", dir="o")),
                Subsignal("sync4",      Pins ("J_3:54", dir="o")),
                Subsignal("active1",    Pins ("J_3:51", dir="o")),
                Subsignal("active2",    Pins ("J_3:49", dir="o")),
                Subsignal("suspended1", Pins ("J_3:52", dir="o")),
                Subsignal("suspended2", Pins ("J_3:50", dir="o")),
                attrs),


            # USB
            ULPIResource("ulpi", 1,
                data="J_3:37 J_3:38 J_3:39 J_3:40 J_3:41 J_3:42 J_3:43 J_3:44",
                clk="J_3:27", clk_dir="o", # this needs to be a clock pin of the FPGA or the core won't work
                dir="J_3:31", nxt="J_3:33", stp="J_3:29", rst="J_3:34", rst_invert=True, # USB3320 reset is active low
                attrs=attrs),

            Resource("usb_aux", 1,
                Subsignal("vbus", Pins("J_3:30", dir="i")),
                Subsignal("id",   Pins("J_3:32", dir="o")),
                Subsignal("sbu1", Pins("J_3:45", dir="i")),
                Subsignal("sbu2", Pins("J_3:46", dir="i")),
                attrs),

            ULPIResource("ulpi", 2,
                data="J_3:17 J_3:18 J_3:19 J_3:20 J_3:21 J_3:22 J_3:23 J_3:24",
                clk="J_3:7", clk_dir="o", # this needs to be a clock pin of the FPGA or the core won't work
                dir="J_3:11", nxt="J_3:13", stp="J_3:9", rst="J_3:14", rst_invert=True, # USB3320 reset is active low
                attrs=attrs),

            Resource("usb_aux", 2,
                Subsignal("vbus", Pins("J_3:10", dir="i")),
                Subsignal("id",   Pins("J_3:12", dir="o")),
                Subsignal("sbu1", Pins("J_3:25", dir="i")),
                Subsignal("sbu2", Pins("J_3:26", dir="i")),
                attrs),

            Resource("i2s", 1,
                Subsignal("sclk",   Pins("J_2:53", dir="o")),
                Subsignal("bclk",   Pins("J_2:54", dir="o")),
                Subsignal("data",   Pins("J_2:55", dir="o")),
                Subsignal("lrclk",  Pins("J_2:56", dir="o")),
                attrs),

            Resource("i2s", 2,
                Subsignal("sclk",   Pins("J_2:57", dir="o")),
                Subsignal("bclk",   Pins("J_2:58", dir="o")),
                Subsignal("data",   Pins("J_2:50", dir="o") if colorlight else Pins("J_2:59", dir="o")),
                Subsignal("lrclk",  Pins("J_2:52", dir="o") if colorlight else Pins("J_2:60", dir="o")),
                attrs),


            # TOSLINK
            Resource("toslink", 1,
                Subsignal("tx", Pins("J_2:49", dir="o")),
                Subsignal("rx", Pins("J_2:51", dir="i")),
                attrs),

            Resource("toslink", 2,
                Subsignal("tx", Pins("J_2:33", dir="o")),
                Subsignal("rx", Pins("J_2:35", dir="i")),
                attrs),

            Resource("toslink", 3,
                Subsignal("tx", Pins("J_2:23", dir="o")),
                Subsignal("rx", Pins("J_2:25", dir="i")),
                attrs),

            Resource("toslink", 4,
                Subsignal("tx", Pins("J_2:18", dir="o") if colorlight else Pins("J_2:7", dir="o")),
                Subsignal("rx", Pins("J_2:9", dir="i")),
                attrs),


            # Debug
            SPIResource(0, clk="J_2:12", copi="J_2:8", cipo=None, cs_n="J_2:10", attrs=attrs),
            #UARTResource(0, tx="J_2:14", rx="J_2:16", attrs=attrs),

            Resource("debug", 0, Pins("J_2:44", dir="o")),
            Resource("debug", 1, Pins("J_2:46", dir="o")),
            Resource("debug", 2, Pins("J_2:48", dir="o")),
            Resource("debug", 3, Pins("J_2:42", dir="o")),
        ]

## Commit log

2021-07-17 use pid.codes test PID
2021-07-20 fix sample rate resolution
2021-08-05 parameterize number of channels and wire usb out stream to ADAT tramsmitter
2021-08-12 implement rate feedback and make IN frame bytes follow out frame bytes
2021-08-12 refactor debug LEDs/GPIOs
2021-08-25 usb_stream_to_channels: remove debug print
2021-09-03 channels_to_usb_stream: Handle the case that the endpoint does not read the expected number of bytes, eg after a change of altsettings, when the number of channels change
2021-09-11 QMTech XC7A35T board finally works with Tobias Müller's Pmod and the QMTech daughterboard.
2021-09-11 QMTech 10CL006 board works with Tobias Müller's Pmod and the QMTech daughterboard.
2021-10-06 Add baseboard EDA files and adjust platform files accordingly
    [BOM-adatface_baseboard.csv, QFN-32-1EP_5x5mm_P0.5mm_EP3.3x3.3mm.step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]
2021-10-06 rename top level submodules according to board
2021-10-07 PCB: add 3d models for connectors
    [HRO TYPE-C-31-M-12.step, PLT133_T10.step, adatface_baseboard.kicad_pcb]
2021-11-06 add debug display and invert suspended LEDs
    [adatface_rev0_baseboard.py]
2021-11-10 fix audio input frame size calculation
2021-11-21 channels_to_usb: fix: don't discard valid samples on underrun
2021-11-25 car: tighten CDC timings
2021-11-25 pcb: update to KiCAD 6
    [adatface_baseboard.kicad_pcb]
2021-11-26 channels_to_usb_stream: fix bug: whole USB frame misaligned
2021-11-30 Fix bugs in rev0
    [adatface_baseboard.kicad_pcb, adatface_baseboard.kicad_sch]
2021-12-01 fix board stackup to JLCPCB specs
    [adatface_baseboard.kicad_pcb]
2021-12-03 hardware: fix header width and 3d model paths
    [adatface_baseboard.kicad_pcb]
2021-12-03 add WIP case design
    [ADATFaceCase.FCStd]
2021-12-03 case: fix height and chamfer case at the end
    [ADATFaceCase.FCStd]
2021-12-04 case: add mounts
    [ADATFaceCase.FCStd]
2021-12-05 case: fine tune parameters
    [ADATFaceCase.FCStd]
2021-12-05 case: convert top lid case into bottom lid case
    [ADATFaceCase.FCStd]
2021-12-05 case: Add BottomRightSupport
    [ADATFaceCase.FCStd]
2021-12-05 case: add lightpipe holes
    [ADATFaceCase.FCStd]
2021-12-05 case: add lightpipe chamfer
    [ADATFaceCase.FCStd]
2021-12-05 case: add lightpipe dummys
    [ADATFaceCase.FCStd]
2021-12-06 case: add LED legend
    [ADATFaceCase.FCStd]
2021-12-06 case: add debug LED holes and lightpipes
    [ADATFaceCase.FCStd]
2021-12-06 case: case body is done
    [ADATFaceCase.FCStd]
2021-12-06 case: case body chamfers, add screws
    [ADATFaceCase.FCStd]
2021-12-07 fix closed bottom mounts
    [ADATFaceCase.FCStd]
2021-12-08 adapt case height to correct value and parameterize height of letters
    [ADATFaceCase.FCStd]
2021-12-08 add missing USB descriptors file, and yay, we got our own USB device ID
2021-12-09 ila.py: adapt to new USB device ID
2021-12-09 update .gitignore to exclude KiCAD backups
2021-12-09 channels_to_usb: make sure that the input of the module does not drop samples
2021-12-15 bundle_multiplexer: allow for inactive bundles (ie ADAT cable not plugged in)
2021-12-15 refactor: extract methods for calculating audio input frame size and rate feedback
2021-12-15 activate and wire up all 4 ADAT transmitters/receivers
2021-12-16 fix missing ready wire
2021-12-17 bundle_multiplexer: fix missing last wire, add debug signals, add ILA signal set
2021-12-17 wire ADAT leds to ADAT receivers
2021-12-22 sync debug: more samples and correct samplerate
2021-12-23 Now it mostly seems to work, with the ILA enabled and at that place. But we still are losing samples at input.
2021-12-23 bundle_multiplexer: have the receiver FIFOs three audio samples
2021-12-23 discard audio input samples if the audio in endpoint is not active to prevent buildup in FIFOs
2021-12-24 debug where the extraneous received samples come from
2021-12-25 ILA: monitor transmit and receive frame rates
2021-12-27 insert missing cdc for number of channels
2021-12-27 ILA: debug more frame counts
2021-12-29 ILA: configure to monitor frame rates throughout the signal path
2021-12-30 ILA/Debug LED matrix: add receiver rate debug and add graphical FIFO level bars
2021-12-30 factor out debug LED array into its own method and deactivate by default
2021-12-30 debug LED matrix: add back underflow count
2021-12-31 extract stereo signal from USB out stream and wire it into DAC1
2022-01-01 wire up second DAC
2022-01-01 don't wire both dacs to channels 0/1
2022-01-01 wire the second DAC to main stereo pair if two channel mode is active
2022-01-03 wire up channel stream combiner
2022-01-04 require package wheel
2022-01-04 require setuptools and wheel
2022-01-05 fix channel combiner and add basic test case
2022-01-06 debug led display: use comb domain instead, we don't care about timing here. use sync domain, usb doesn't work for some reason
2022-01-06 wire up USB2 audio input to USB1 audio output (upper channels)
2022-01-07 fix bug: usb2_ep2_in did not have the needed frame size set
2022-01-11 add MIDI (has bugs), factor out ILA and debug LEDs into debug.py, add second debug LED panel
2022-01-12 request handler: get rid off StallOnlyRequestHandler
2022-01-17 README: add case image
2022-01-17 README: case image, again
2022-01-20 fix wrong audio in frame size calculation.
2022-04-13 Added an optional convolver as dsp for the dac1 output. The convolver can be enabled with the USE_CONVOLUTION flag. Once the design has been synthesized with USE_CONVOLUTION enabled you can enable th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
2022-04-27 add first colorlight version. USB works, ADAT doesn't
    [adatface_rev0_baseboard.py]
2022-06-11 add minerva based soc with CPU/UART/Timer
2022-08-05 Fix missing symbol and footprint libraries for toslink
    [adatface_baseboard.kicad_pcb, adatface_baseboard.kicad_sch]
2022-08-05 change toslink footprints to T8 variation
    Footprint is the same except for the edition of NPTH for
    plastic mounting feet, so either T8 or T10 versions can
    be used.
    [PLR135_T8.stp, adatface_baseboard.kicad_pcb, adatface_baseboard.kicad_sch]
2022-08-05 Update JLCPCB files
    [BOM-adatface_baseboard.csv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]
2022-08-06 fix USB-C port POS rotation
    [BOM-adatface_baseboard.csv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]
2022-08-06 Fix power trace board clearance issue, adjust board width for TOSLINK port clearance
    [adatface_baseboard-CuBottom.gbr, adatface_baseboard-CuIn1.gbr, adatface_baseboard-CuIn2.gbr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]
2022-08-06 fix POS file
    [CPL-adatface_baseboard.csv, POS-adatface_baseboard.csv]
2022-08-06 length match USB PHY traces
    [adatface_baseboard.kicad_pcb]
2022-08-06 adjust PHY1 diff pair trace widths
    [adatface_baseboard.kicad_pcb]
2022-08-06 move trace which was too close to the upper PHY diff pairs
    [adatface_baseboard.kicad_pcb]
2022-08-06 fix hole-hole spacing issues
    [POS-adatface_baseboard.csv, adatface_baseboard-CuBottom.gbr, adatface_baseboard-CuIn1.gbr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]
2022-08-07 fix DRC errors
    [POS-adatface_baseboard.csv, adatface_baseboard-CuBottom.gbr, adatface_baseboard-CuIn1.gbr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]
2022-08-08 remove 'custom' design rules causing trouble
    [adatface_baseboard.kicad_pcb]
2022-08-09 baseboard rev0.1: Fix DRC rules with new KiCAD version, length matched USB PHY traces, more ground vias, fix trace spacing, ground headers
    [BOM-adatface_baseboard.csv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]
2022-08-09 fix reference designators on GND headers
    [adatface_baseboard.kicad_pcb]
2022-08-09 length and 90Ohm impedence match D- and D+
    [BOM-adatface_baseboard.csv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]
2022-08-09 Add nikitalita to the credits on the board. Also adjust diff pair of the top PHY
    [POS-adatface_baseboard.csv, adatface_baseboard-CuBottom.gbr, adatface_baseboard-CuIn1.gbr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]
2022-08-09 fix diff pair run on both top and bottom USB interfaces
    [POS-adatface_baseboard.csv, adatface_baseboard-CuBottom.gbr, adatface_baseboard-CuIn1.gbr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]

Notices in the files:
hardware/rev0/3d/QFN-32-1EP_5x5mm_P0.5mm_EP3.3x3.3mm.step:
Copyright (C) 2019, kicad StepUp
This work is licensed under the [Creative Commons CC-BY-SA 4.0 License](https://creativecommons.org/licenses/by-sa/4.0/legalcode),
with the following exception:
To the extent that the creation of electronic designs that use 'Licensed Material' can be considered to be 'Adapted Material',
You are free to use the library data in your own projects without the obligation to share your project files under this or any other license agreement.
